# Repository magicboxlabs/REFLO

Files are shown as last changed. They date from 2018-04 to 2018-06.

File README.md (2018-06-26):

Setup
===================

1.In the BOX
-------------------
* **[Quick start guide](https://github.com/magicboxlabs/REFLO/blob/master/Documents/openthebox.pdf)** - Items in the box

2.Setup REFLO
-------------------
* **[Assemble guide](https://github.com/magicboxlabs/REFLO/blob/master/Documents/Assembly.pdf)** - Setup each modules
* **[Connect to the earth terminal](https://github.com/magicboxlabs/REFLO/blob/master/Documents/How%20to%20connect%20to%20the%20earth%20terminal.pdf)** - Additional working guide
* **[Setting the PCB](https://github.com/magicboxlabs/REFLO/blob/master/Documents/REFLO%20PAN%20USER%20GUIDE.pdf)** - REFLO PAN User Guide
* **[Warning](https://github.com/magicboxlabs/REFLO/blob/master/Documents/warning.pdf)** - Special Attention

3.Setup Software
-------------------
* **[iOS](https://itunes.apple.com/us/app/simblee-for-mobile/id1009048292?mt=8)** - iOS Mobile App
* **[Android](https://play.google.com/store/apps/details?id=com.simblee.simbleeformobile&hl=en)** - Android Mobile App

4.How to Operate
-------------------
* **[Operation guide](https://github.com/magicboxlabs/REFLO/blob/master/Documents/operation.pdf)** - UI Operation

Design Information
===================

1.Mechanical Parts
-------------------
* **[Mechanical Parts Data](https://github.com/magicboxlabs/REFLO/tree/master/parts)** - Chassis, 3D print parts, Furnace

2.PWB
-------------------
* **[Schematic Drawing](https://github.com/magicboxlabs/REFLO/blob/master/schematic/REFLO%20schematic.pdf)** - Gerber Data, Parts List
* **[PWB Data](https://github.com/magicboxlabs/REFLO/tree/master/gerber)** - Gerber Data, Parts List

3.Software
-------------------
* **[Source Code for iOS](https://github.com/magicboxlabs/REFLO/tree/master/software)** - Control Software Source Code
* **[Source Code for Android](https://github.com/magicboxlabs/REFLO/tree/master/software)** - Control Software Source Code

Reference
===================
* **[CrowdSupply REFLO](https://www.crowdsupply.com/magicbox/reflo)**
* **[Hacksterio REFLO](https://www.hackster.io/magicbox/ble-reflow-oven-controller-reflo)**
* **[Hacksterio SHAKEYs](https://www.hackster.io/ebaera/voice-controlled-shakeys)**
* **[Hacksterio actual example](https://www.hackster.io/tka1988/baking-your-pcbs-with-super-compact-reflow-oven-388e2c)**

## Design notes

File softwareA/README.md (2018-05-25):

Software for Android
-------------------
* **[Simblee](https://www.simblee.com/Simblee_Quickstart_Guide_v1.1.0.pdf)** - Arduino IDE for Simblee setup

* Modify variant file
Arduino/Contets/Java/portable/packages/Simblee/hardware/Simblee/1.0.0/variants/Simblee/variant.h     
  #define SPI_INTERFACE        NRF_SPI0  
  #define PIN_SPI_SS           (18u) //  
  #define PIN_SPI_MOSI         (30u) //  
  #define PIN_SPI_MISO         (16u) //  
  #define PIN_SPI_SCK          (17u) //  

* **[Library](https://github.com/FastLED/FastLED)** - RGB RED (FastLED) library

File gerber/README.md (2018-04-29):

Parts List
-------------------
* MPU with BLE - **[RFD77101](https://www.mouser.com/ProductDetail/RF-Digital-Wireless/RFD77101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)** 
* USB Interface FTDI - **[FT231XQ-R](https://www.mouser.com/ProductDetail/FTDI/FT231XQ-R?qs=sGAEpiMZZMvVkErl6zY%252bqYuXoSRwsvKy)**
* USB Connector - **[ZX62D-B-5PA8(30)](https://www.mouser.com/ProductDetail/Hirose-Connector/ZX62D-B-5PA830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)**
* Thermocouple Sensor - **[MAX31855KASA+](https://www.mouser.com/ProductDetail/Maxim-Integrated/MAX31855KASA%2b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)** 
* Motor Driver for Fan/Solenoid - **[DRV8838DSGR](https://www.mouser.com/ProductDetail/Texas-Instruments/DRV8838DSGR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)**
* DC-DC Converter - **[LP2985-33DBVR](https://www.mouser.com/ProductDetail/Texas-Instruments/DRV8838DSGR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)**

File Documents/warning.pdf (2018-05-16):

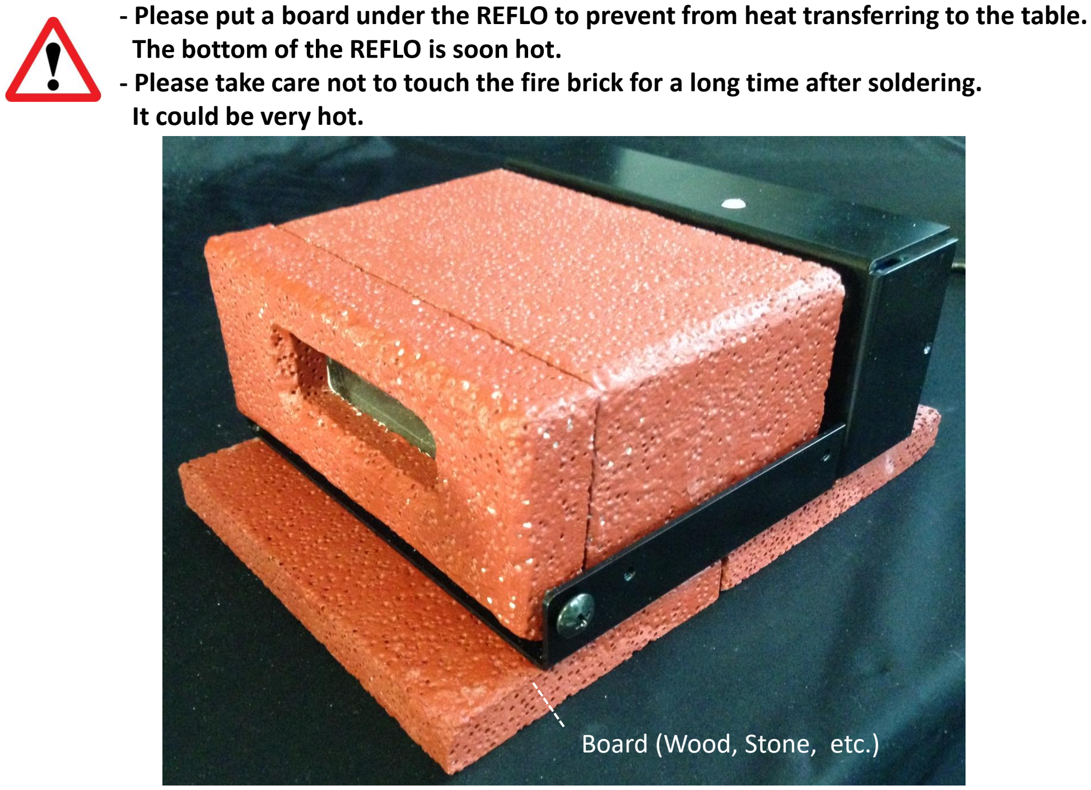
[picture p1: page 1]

Board (Wood, Stone, etc.)

- Please put a board under the REFLO to prevent from heat transferring to the table. The bottom of the REFLO is soon hot.
- Please take care not to touch the fire brick for a long time after soldering.
It could be very hot.

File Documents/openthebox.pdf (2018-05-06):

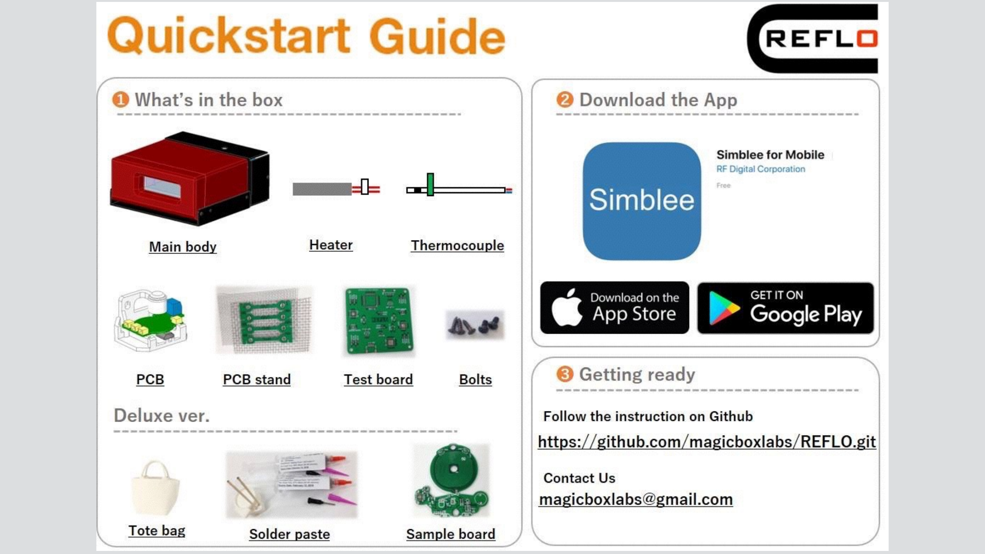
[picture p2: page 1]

Solenoid

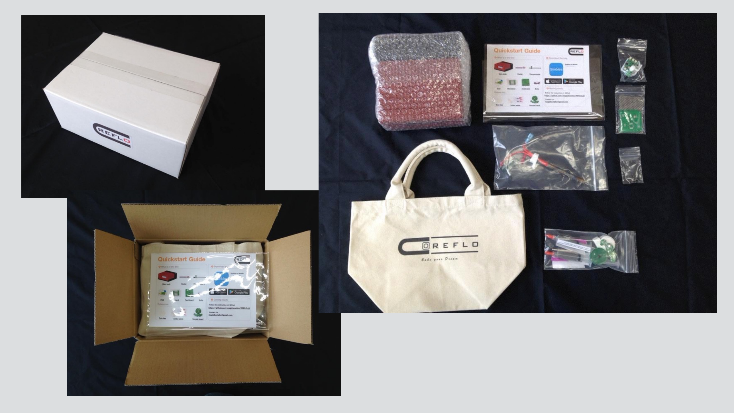
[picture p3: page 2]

Solenoid

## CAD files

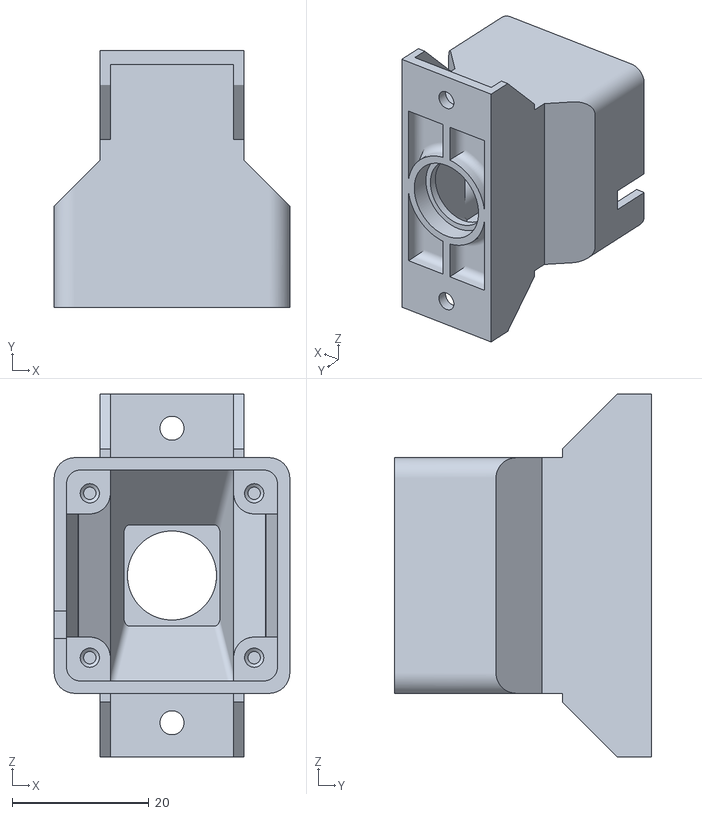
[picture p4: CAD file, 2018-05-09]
parts/Fan Case.stl
34.4 x 37.5 x 53.0

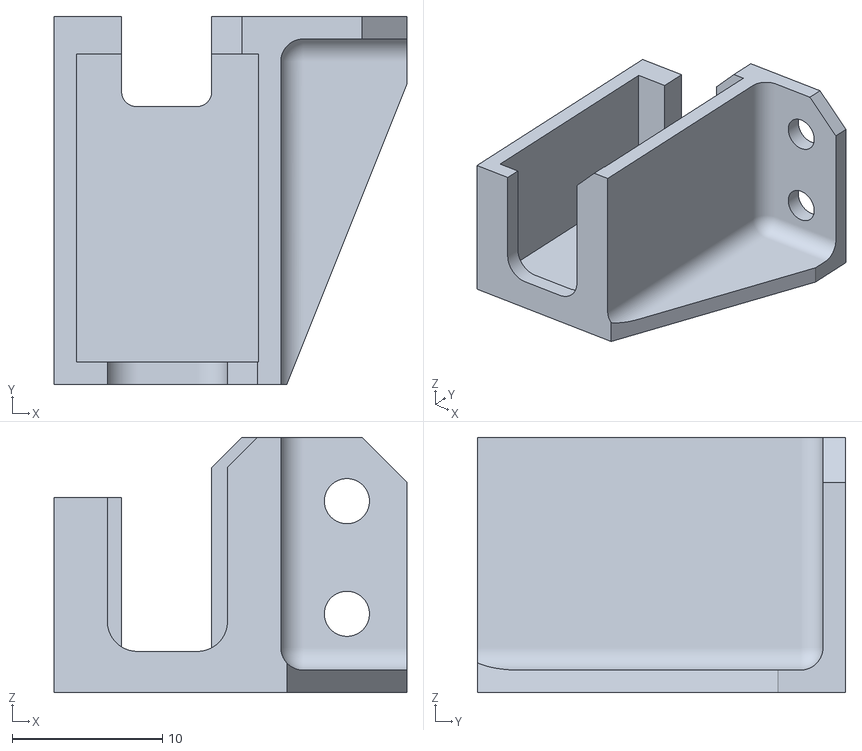
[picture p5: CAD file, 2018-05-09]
parts/Solenoid Holder.stl
23.5 x 24.5 x 17.0

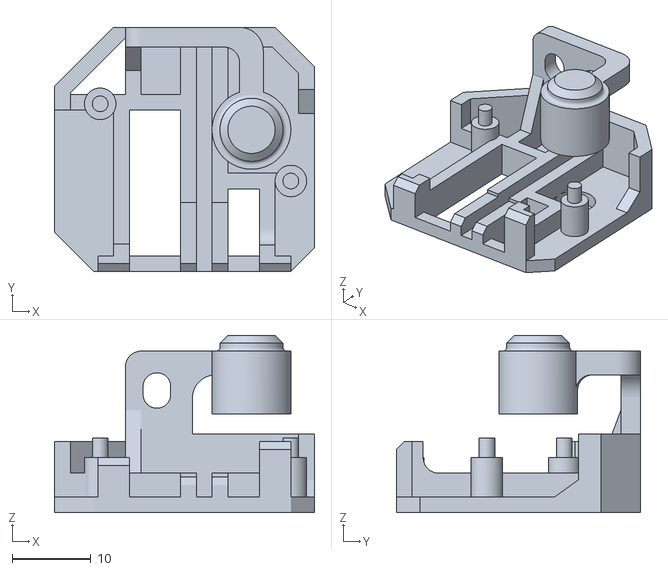
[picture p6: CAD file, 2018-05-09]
parts/PCB CASE.stl
33.0 x 31.0 x 22.5

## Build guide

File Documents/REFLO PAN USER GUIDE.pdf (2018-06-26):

## REFLO PAN USER GUIDE

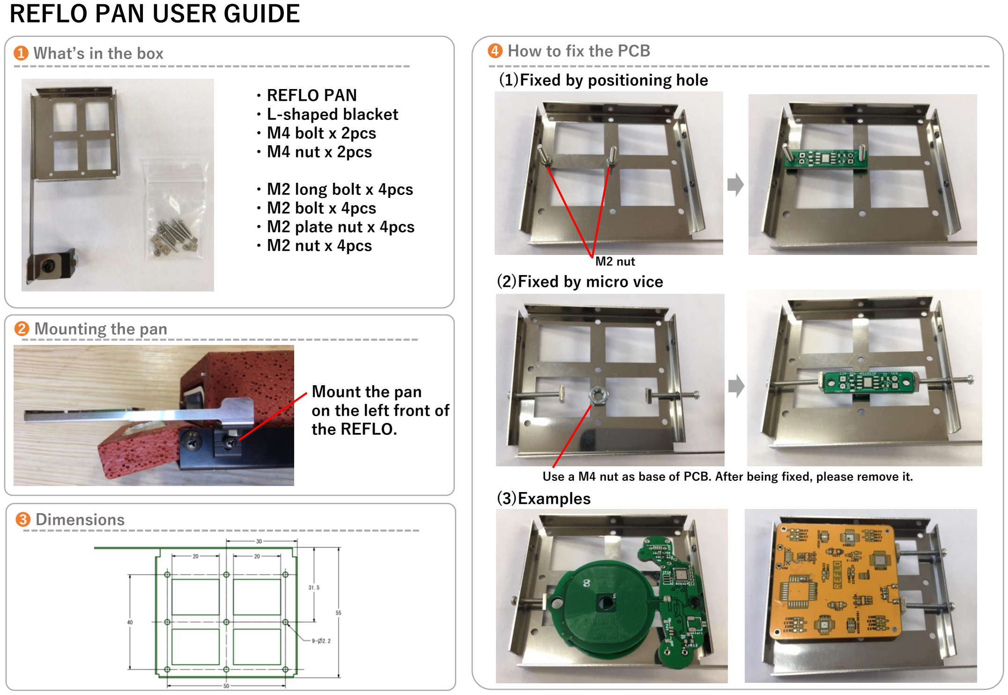
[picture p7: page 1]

❶ What’s in the box | ❹ How to fix the PCB

・REFLO PAN
・L-shaped blacket
・M4 bolt x 2pcs
・M4 nut x 2pcs

・M2 long bolt x 4pcs
・M2 bolt x 4pcs
・M2 plate nut x 4pcs
・M2 nut x 4pcs

❷ Mounting the pan

Mount the pan
on the left front of
the REFLO.

❸ Dimensions

(1)Fixed by positioning hole

(2)Fixed by micro vice

(3)Examples

Use a M4 nut as base of PCB. After being fixed, please remove it.

M2 nut

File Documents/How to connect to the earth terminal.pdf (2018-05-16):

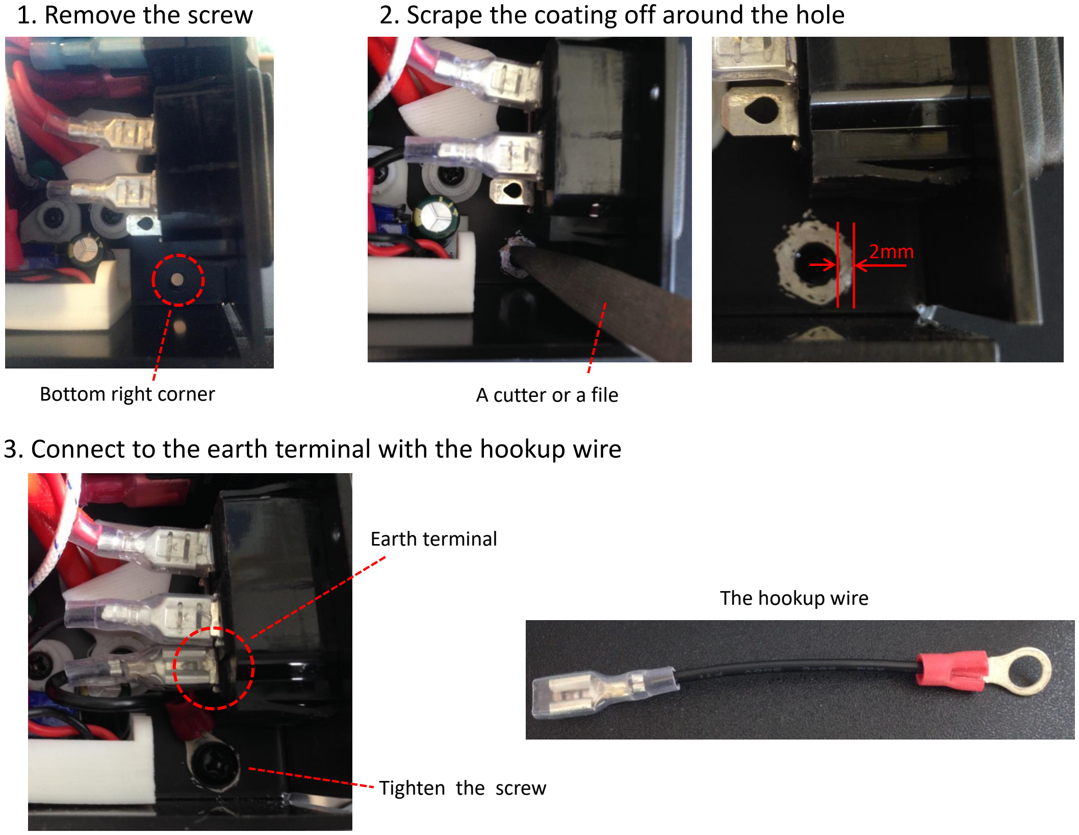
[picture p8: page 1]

1. Remove the screw

Bottom right corner

2. Scrape the coating off around the hole

A cutter or a file

2mm

3. Connect to the earth terminal with the hookup wire

Earth terminal

The hookup wire

Tighten the screw

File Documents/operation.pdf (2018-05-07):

## Starting Application

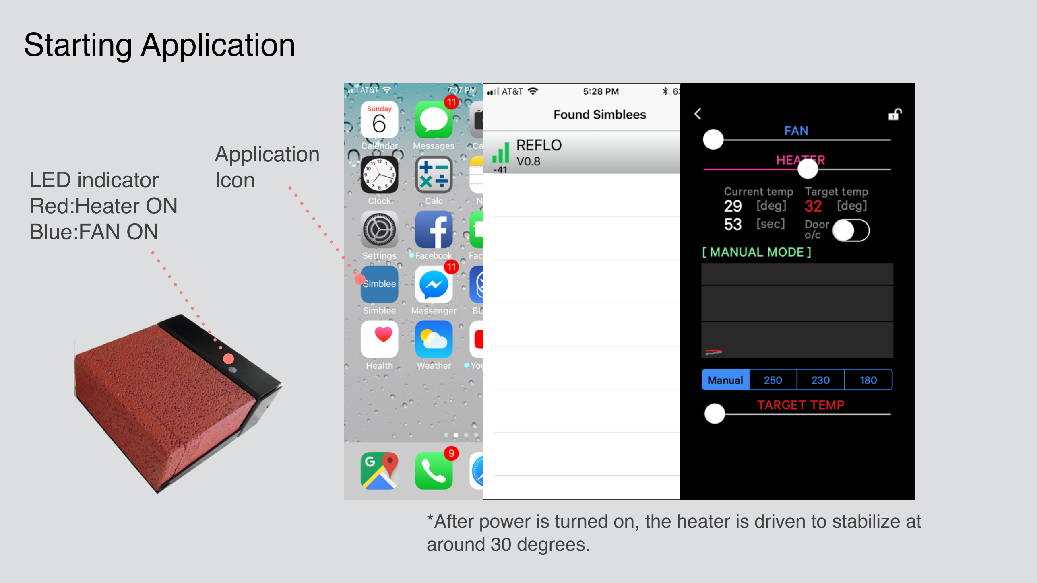
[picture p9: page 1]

Application
Icon

LED indicator
Red:Heater ON
Blue:FAN ON

*After power is turned on, the heater is driven to stabilize at around 30 degrees.

## Manual Mode

Temperature
setting slider

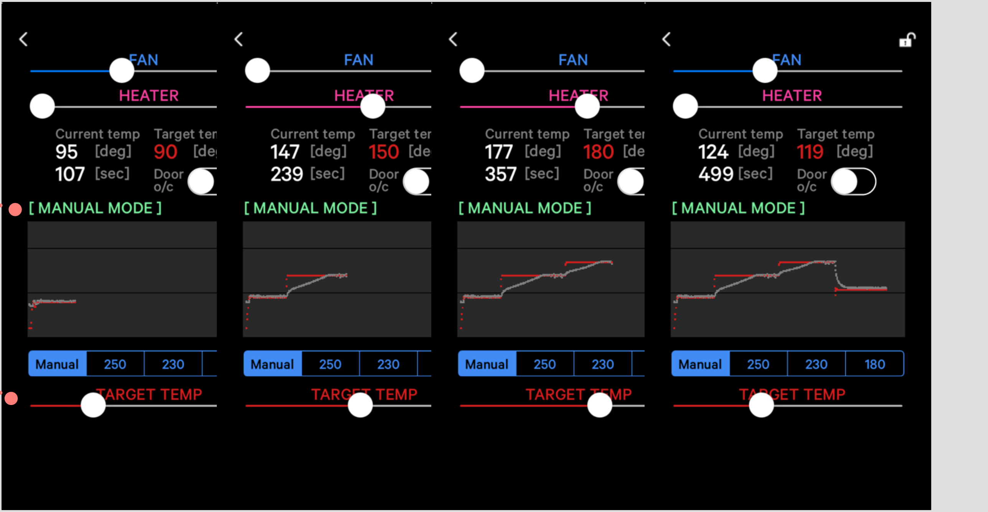
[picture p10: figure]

Set to 90 degrees
by slider

Set to 150 degrees
by slider

Set to 180 degrees
by slider

Set to 119 degrees
by slider

*You can set it to any temperature with the temperature setting slider. The heater and fan automatically adjust the temperature.

Mode
Display

Auto Mode | *Three kinds of temperature profile of 180/230/250 degrees are selected, and heater and fan can work together to automatically execute temperature profile.

Temperature
profile
selector

Mode
Display

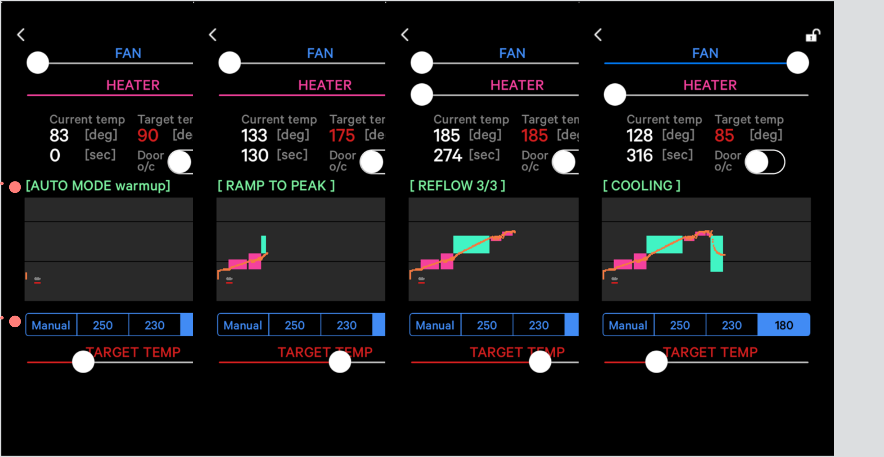
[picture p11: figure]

Warmup | Ramp to Peak
after Soak stage | Reflow stage | Cooling down stage

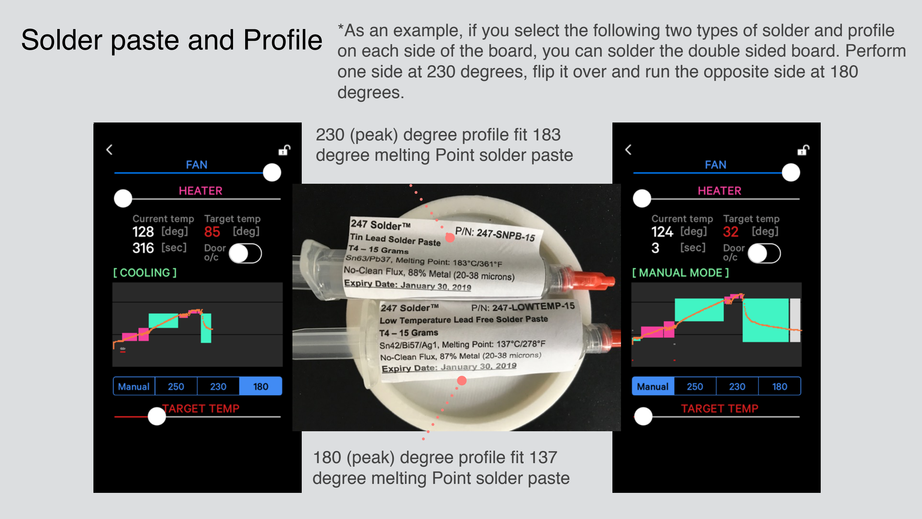
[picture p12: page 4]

Solder paste and Profile *As an example, if you select the following two types of solder and profile on each side of the board, you can solder the double sided board. Perform one side at 230 degrees, flip it over and run the opposite side at 180 degrees.

230 (peak) degree profile fit 183 degree melting Point solder paste

180 (peak) degree profile fit 137 degree melting Point solder paste

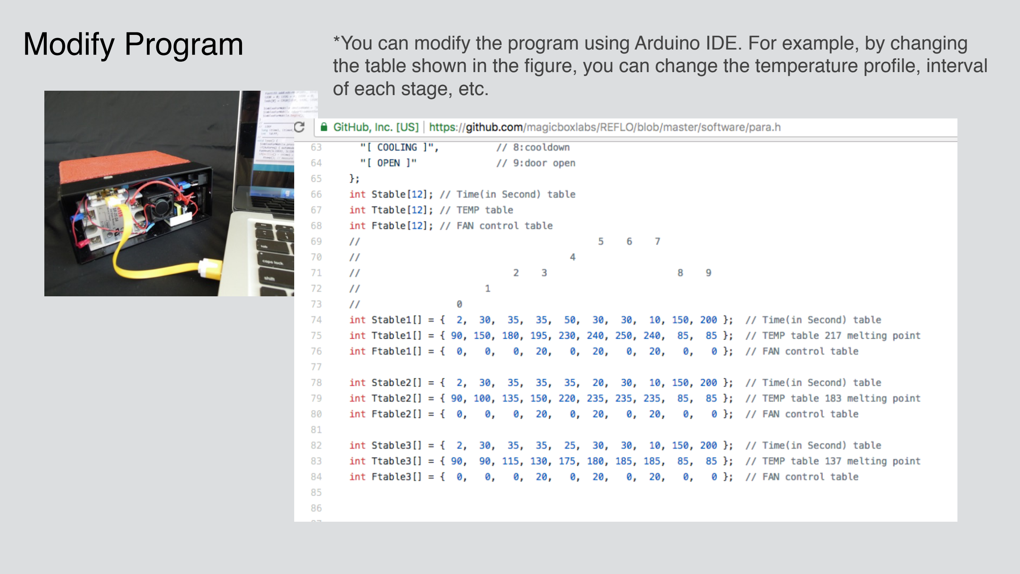
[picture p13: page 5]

Modify Program | *You can modify the program using Arduino IDE. For example, by changing the table shown in the figure, you can change the temperature profile, interval of each stage, etc.

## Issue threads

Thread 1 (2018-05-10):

REFLO lacks chassis ground connection

jmwilson, 2018-05-10:
The assembly directions for REFLO show an unconnected ground tab on the power entry unit, and the unit I received looks the same. I'm concerned this presents a serious electrical shock hazard. Without a chassis ground connection, if there is an electrical fault inside the REFLO, then the metal case can become electrically live at utility voltage (120 VAC in NA). I'd like to suggest emailing all recipients of the REFLO to inform them of this problem, and shipping a ground connection wire to all recipients. I fashioned a connection using hookup wire a pair of crimp terminals.

TKA1988, 2018-05-15:
[How to connect to the earth terminal.pdf](https://github.com/magicboxlabs/REFLO/files/2006779/How.to.connect.to.the.earth.terminal.pdf)
This guide will show you how to connect to the earth terminal. If you need the hookup wire, I will send you.

nikwest, 2018-05-16:
Yes, I did it exactly the same way as TKA1988 suggested.

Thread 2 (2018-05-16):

No simblee connection with Android

TKA1988, 2018-05-16:
Here is the report from Android user.
---------------------------------------------------------------------------------------------------
The REFLO powers up and stabilizes at the preset initial temperature. I can see and Bluetooth pair with the REFLO from the phone and from a computer. So the REFLO does appear to be working correctly.

However the Simblee app (Android) does not seem to connect. It prints the lines "Found Simblees" and "Select Simblee" regardless of whether the REFLO is turned on or not. No other display or interaction appears possible. I've also uninstalled and reinstalled the app, making sure it has been given all requested permissions.

It looks as though my Android 8.0.0 phone (Sony Xperia XZ) is not supported. It does connect with my Galaxy S tablet (Android 6.0.1) but the app doesn't work correctly (repeatedly disconnects, can't control temperature in Manual mode).

It would seem I'm stuck until Simblee provides Android 8.0 support. Could it be possible to communicate with the controller via a BLE serial terminal session or directly through the USB connector? Seems unfortunate to be this close!

TKA1988, 2018-05-27:
The software for Android was updated. Please check the following.
https://github.com/magicboxlabs/REFLO/tree/master/software

ppelleti, 2018-10-03:
> The software for Android was updated. Please check the following.
> https://github.com/magicboxlabs/REFLO/tree/master/software

So, to be clear, I need to recompile the software and upload it to the REFLO using the USB connector on the circuit board?

TKA1988, 2018-10-04:
Yes, you need to do. And don't forget to power supply from DC converter to the PCB when you upload it.

jdimpson, 2019-01-04:
I need more help than this. I can get simblee for mobile on Android to connect and start a bake, but after that the app will not stay connected.

Are you saying the fix is to change the Arduino code on the reflo?  Where are the instructions for this? The simblee.com link provided in REFLO/software folder is broken.

Does this mean that I need different Arduino code on the REFLO depending on whether I control via Apple or Android? This simblee stuff is terrible.

What do you mean "don't forget to power supply from DC converter to the PCB when you upload it." Do you mean to provide DC power to the internal board? How? How do I upload the firmware? I assume it had a serial or usb header, but where can I see the documentation for that?

TKA1988, 2019-01-05:
@jdimpson Yes, you need to change the Arduino code on the PCB by micro USB. I attached quick start guide for Simblee IDE installation. When you upload the code, you have to turn on power switch of REFLO so that it supplies 5V to the PCB. The code for Android is [here.]  (https://github.com/magicboxlabs/REFLO/tree/master/software)
If it is not going to work, we could send you the PCB optimized for Android.
We are sorry for inconvenience. Please keep us updated on this matter.
[Simblee_Quickstart_Guide_v1.0.pdf](https://github.com/magicboxlabs/REFLO/files/2729275/Simblee_Quickstart_Guide_v1.0.pdf)

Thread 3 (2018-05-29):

Missing step in Assembly Instructions for wood screws on in back panel

jdimpson, 2018-05-29:
Hello!

This is relatively minor. The [Assembly Instructions](https://github.com/magicboxlabs/REFLO/blob/master/Documents/Assembly.pdf) should mention to use the wood screws to hold the back wood panel into the housing.

Also, I originally received 3 wood screws and 2 machine screws. I only used 2 wood screws and 1 machine screw. Is that the expected result? Thanks.

TKA1988, 2018-05-31:
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

Thanks for your comment. I attached the screw arrangement at the back-side.

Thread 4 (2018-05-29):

Request instructions for PCB stand

jdimpson, 2018-05-29:
Could you provide instructions for assembling and use the PCB stand? Or perhaps they already exist and I missed them. Thanks!

TKA1988, 2018-05-31:
You can download the stl data as follow and build it with 3D printer.
https://github.com/magicboxlabs/REFLO/blob/master/parts/PCB%20CASE.stl

Thanks,

ppelleti, 2018-10-03:
Perhaps I misunderstood the question, but I think @jdimpson was referring to this:

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

Although I can make a few guesses, it's not entirely obvious to me how this is meant to be assembled.

TKA1988, 2018-10-04:
Oh, I misunderstood that. Here is the assembled PCB stands.
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
You can put it inside the REFLO.
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
But if you have a REFLO pan, you don't need to use the stand.

jdimpson, 2018-10-12:
Yes, I was referring to this. But I use the pan now. Thank you!

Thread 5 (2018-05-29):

Request parts BOM for Test Board and Sample Board

jdimpson, 2018-05-29:
Is there a Bill of Materials that I can use to get components so I can bake the Test Board and Sample Board? Thanks!

TKA1988, 2018-05-31:
You can access to the information about Sample Board as follow.
https://www.hackster.io/ebaera/voice-controlled-shakeys-b93512

Thanks,

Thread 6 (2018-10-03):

Need to connect fan in assembly instructions

ppelleti, 2018-10-03:
In the assembly instructions, there is no mention of connecting the fan to the circuit board.  However, from the pictures I can see this was done in between the "Connect solenoid" and "Connect Solid State Relay" steps.

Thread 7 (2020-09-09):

Simblee replacement?

nikwest, 2020-09-09:
Unfortunately Simblee does not exist anymore and also the old version does not work anymore. Is anybody still using REFLO? is there a way to control it without Simblee?

TKA1988, 2020-09-11:
@nikwest We are planning to make a stand-alone version of REFLO as attached.  We could send you the parts kit for it when we get ready.
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

nikwest, 2020-09-30:
ok, maybe I just also look at the code for now to see if I can do something myself.

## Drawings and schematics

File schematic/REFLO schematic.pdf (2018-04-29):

# REFLO

## 1. VCC

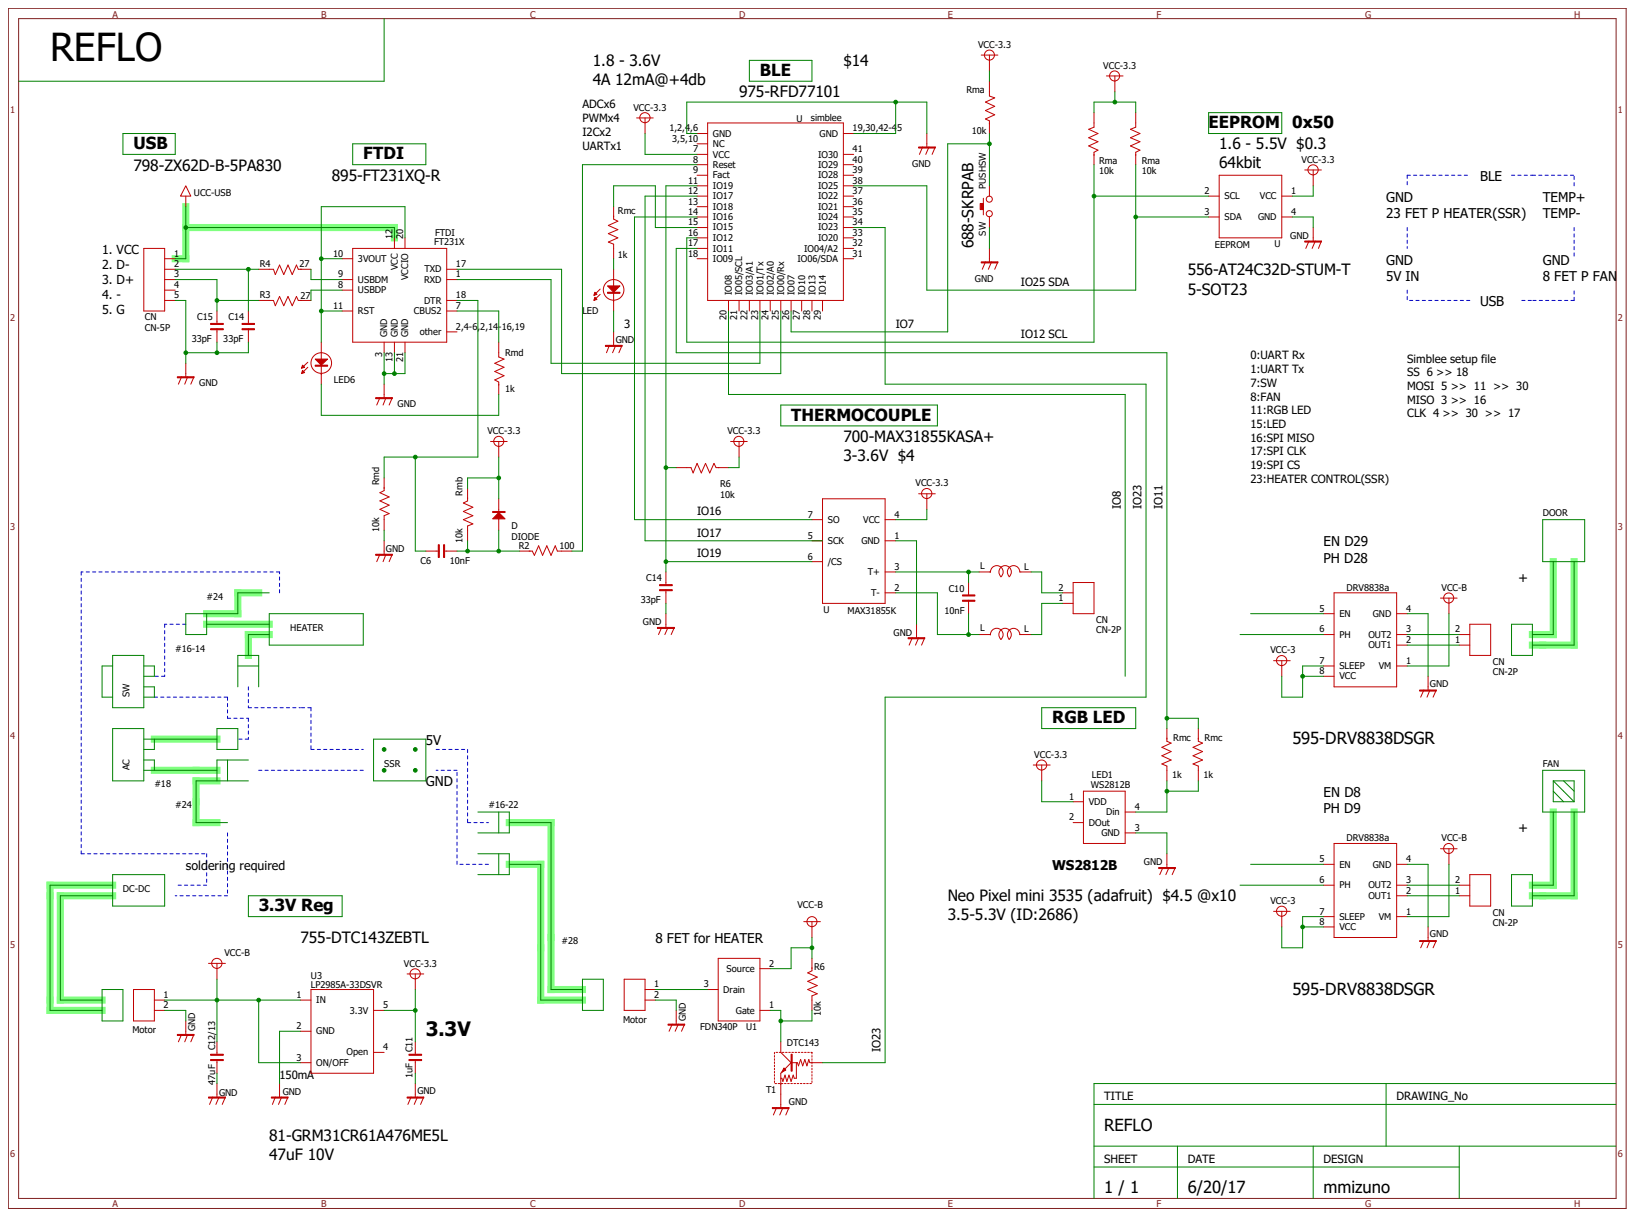
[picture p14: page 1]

0:UART Rx 1:UART Tx 7:SW

Simblee setup file SS 6 >> 18 MOSI 5 >> 11 >> 30 MISO 3 >> 16 CLK 4 >> 30 >> 17

Neo Pixel mini 3535 (adafruit) $4.5 @x10

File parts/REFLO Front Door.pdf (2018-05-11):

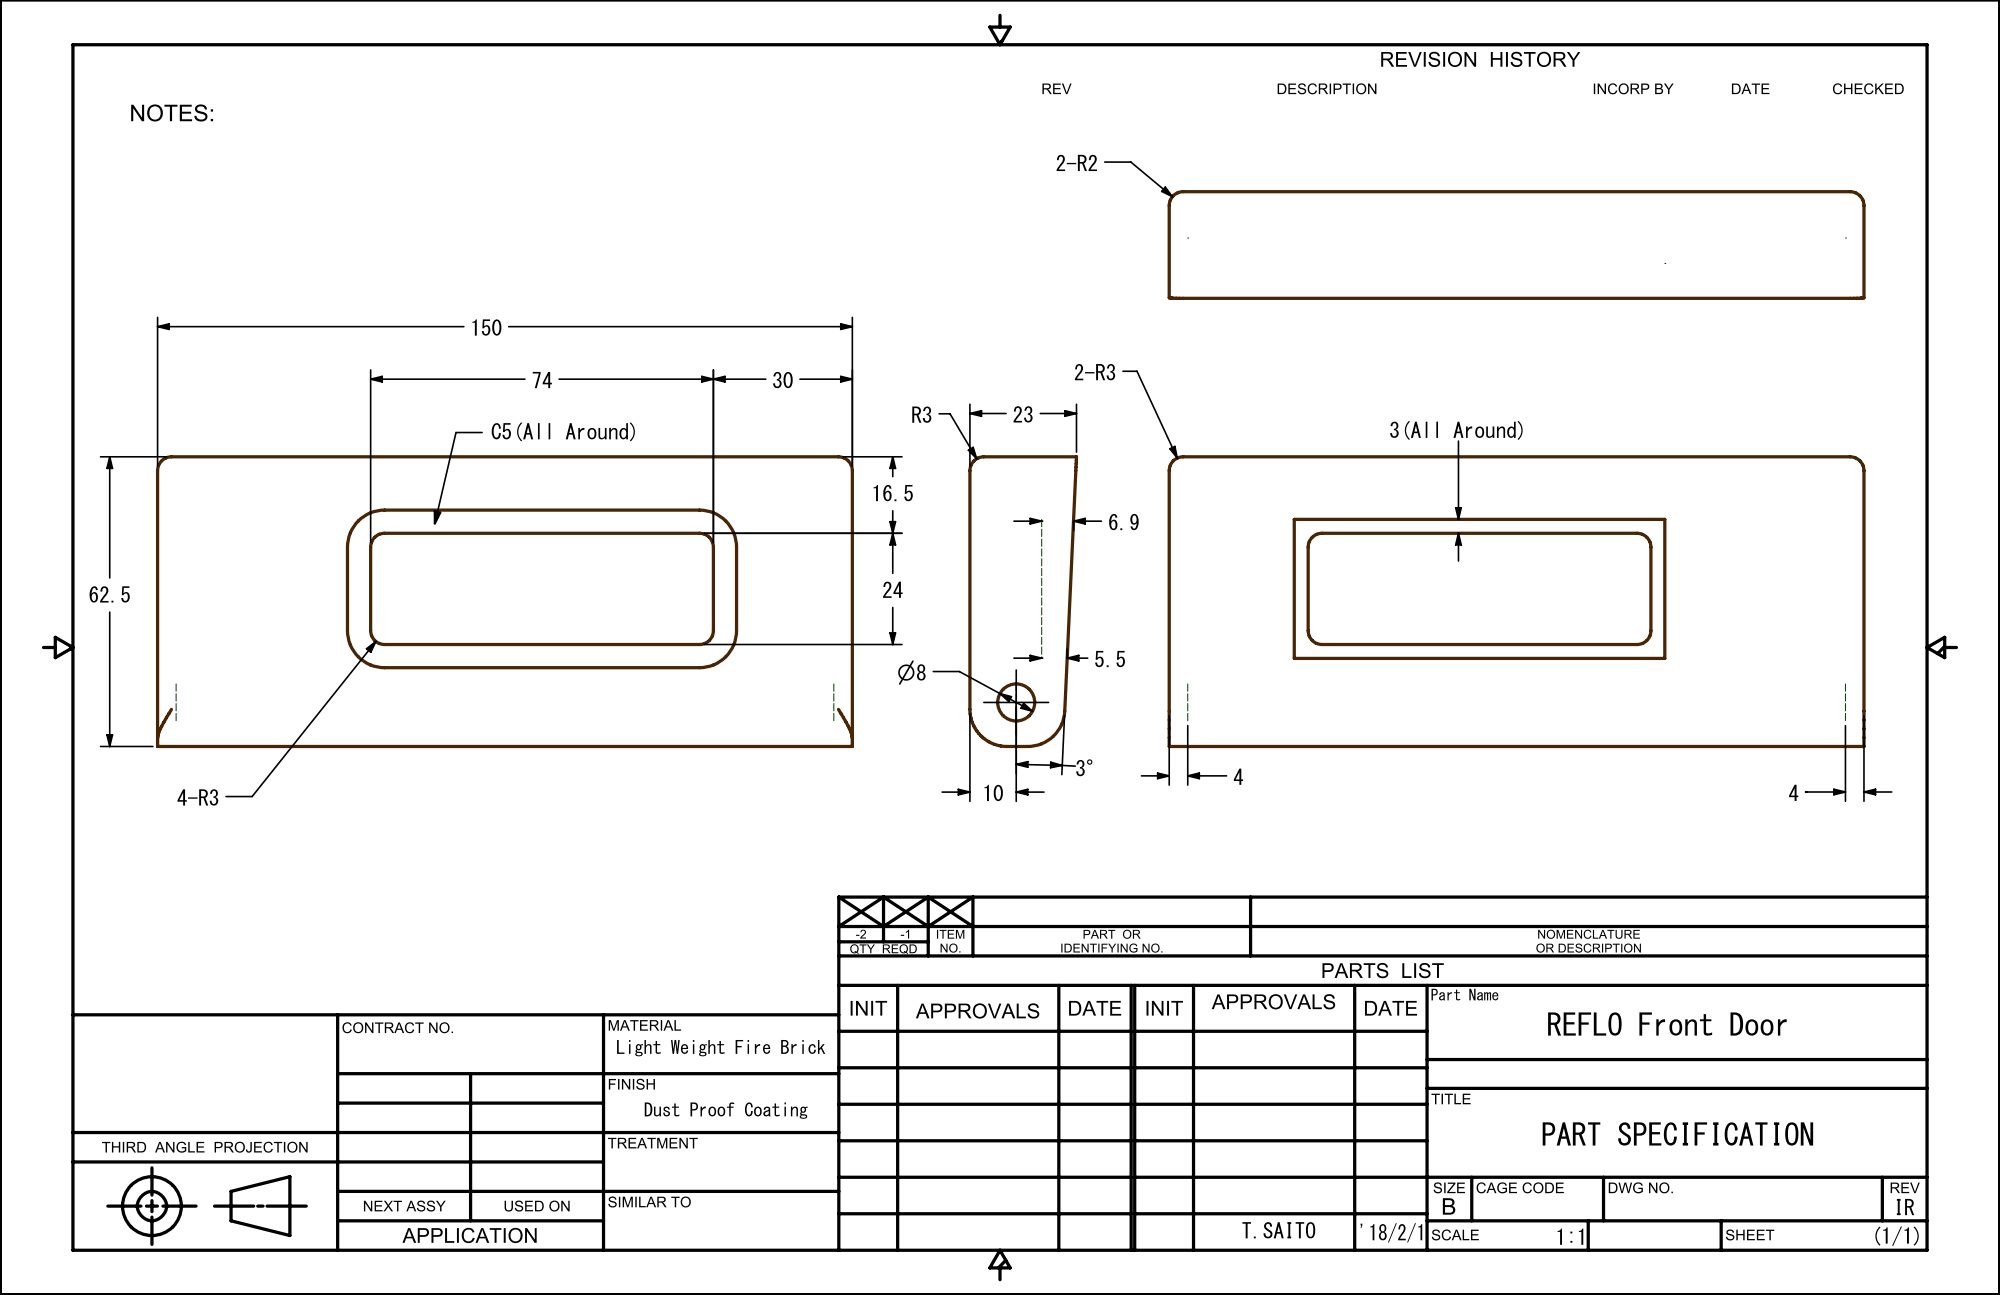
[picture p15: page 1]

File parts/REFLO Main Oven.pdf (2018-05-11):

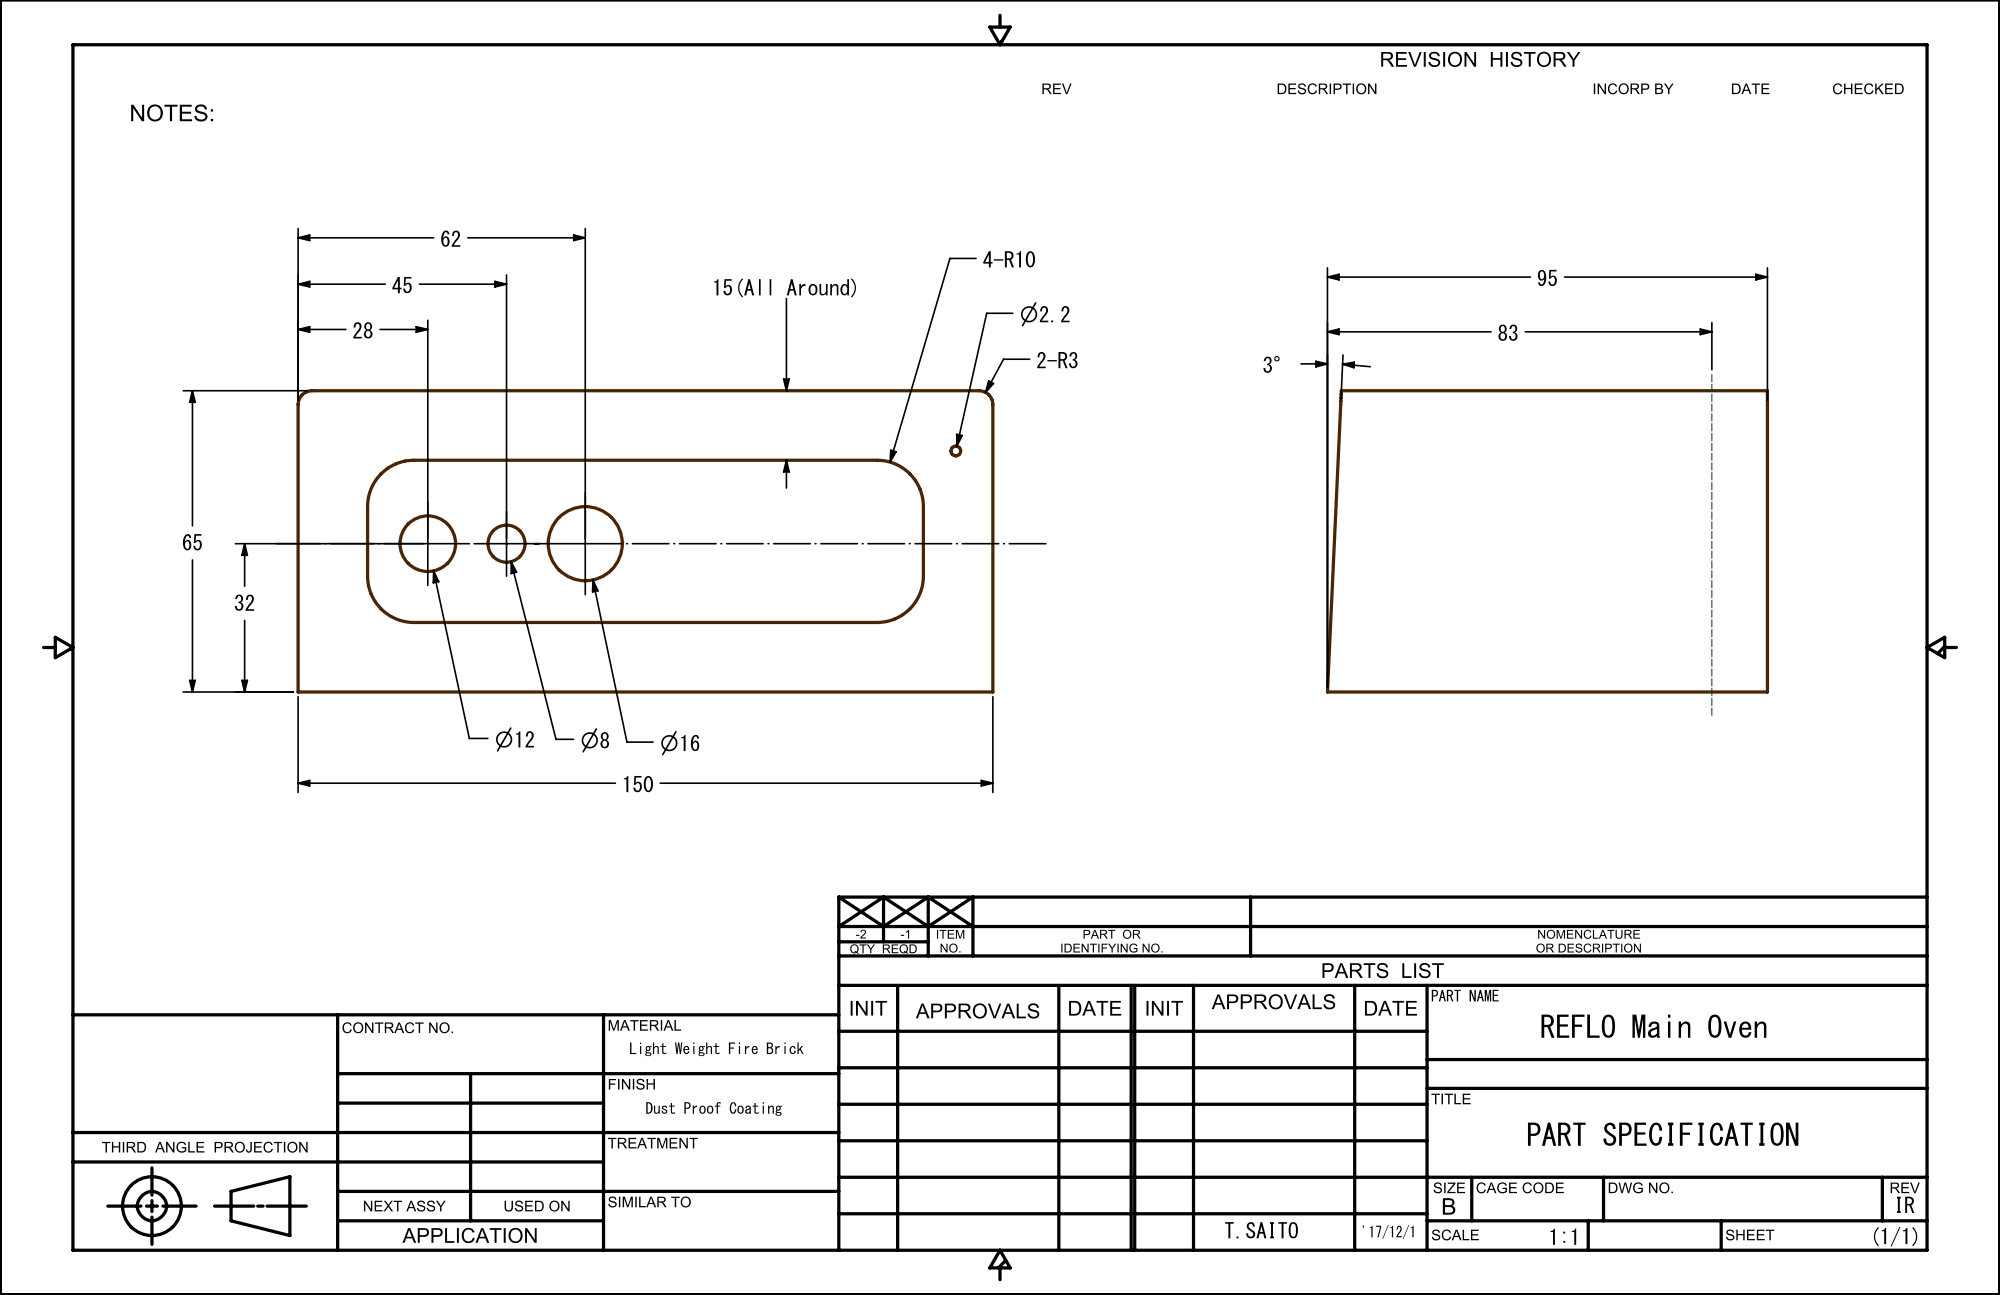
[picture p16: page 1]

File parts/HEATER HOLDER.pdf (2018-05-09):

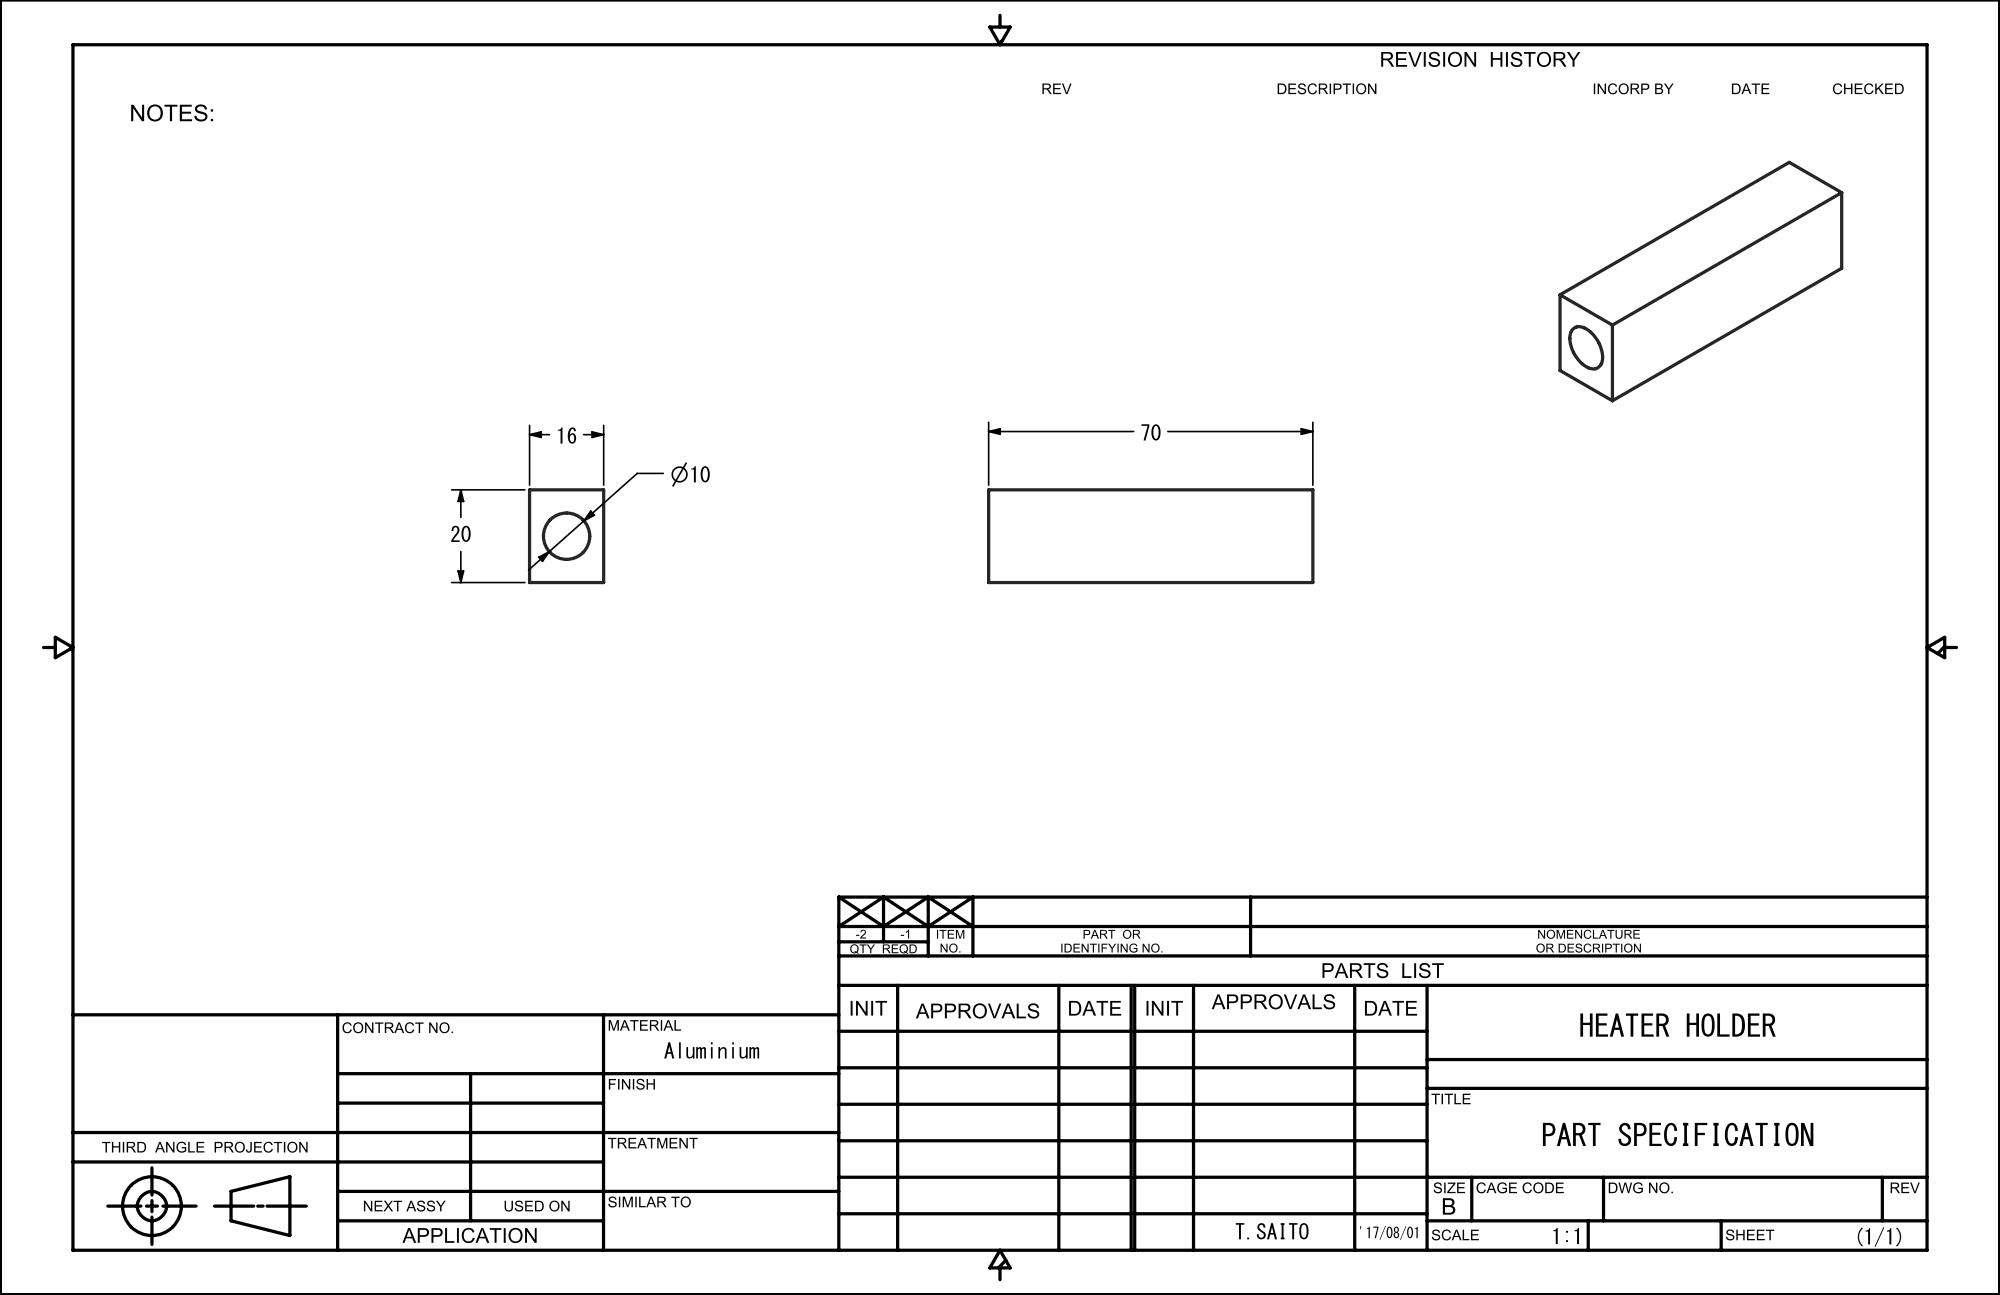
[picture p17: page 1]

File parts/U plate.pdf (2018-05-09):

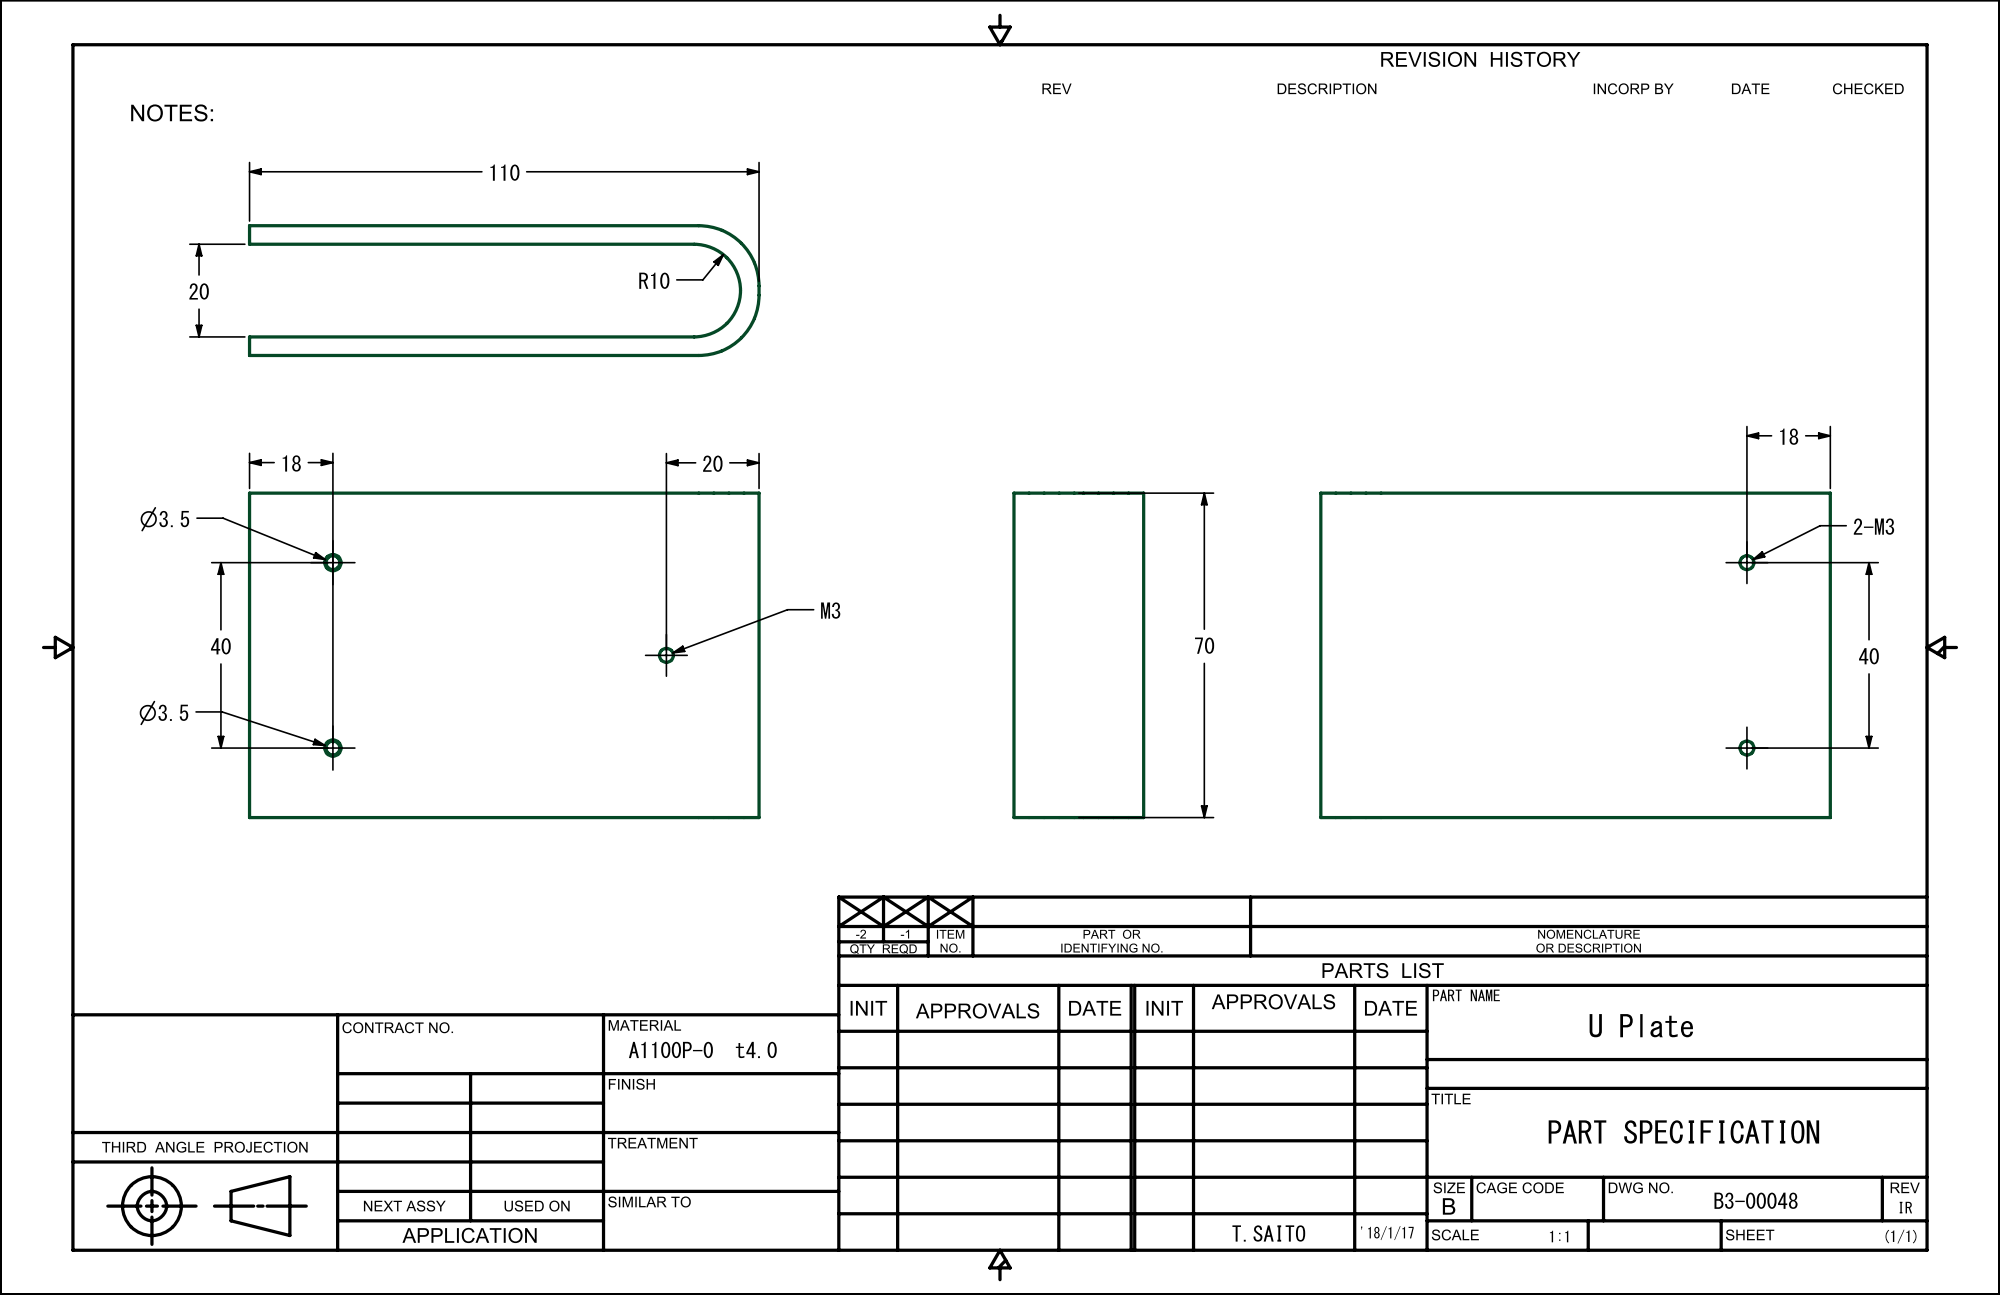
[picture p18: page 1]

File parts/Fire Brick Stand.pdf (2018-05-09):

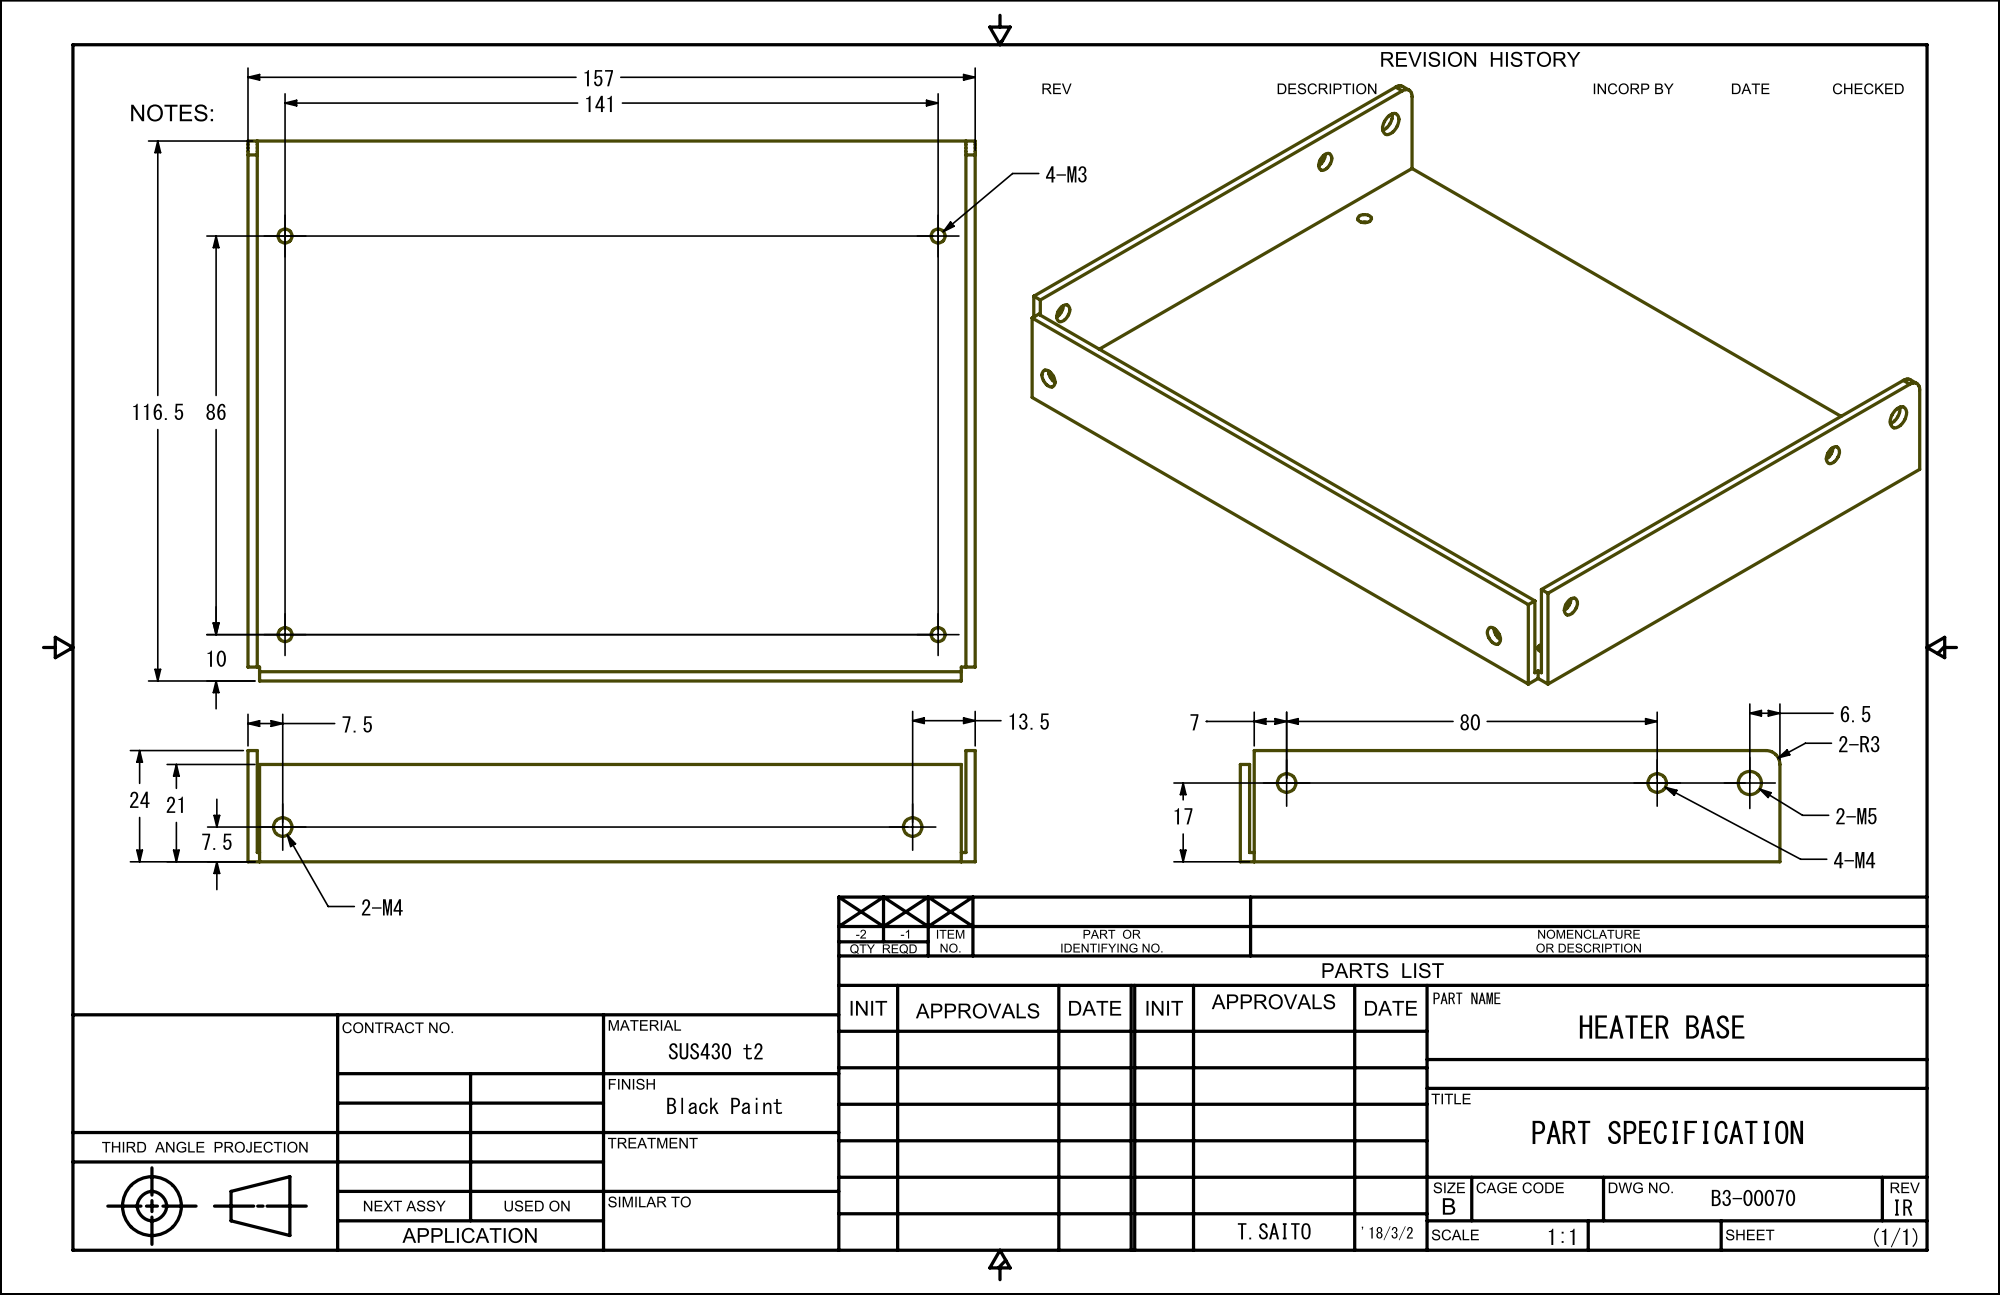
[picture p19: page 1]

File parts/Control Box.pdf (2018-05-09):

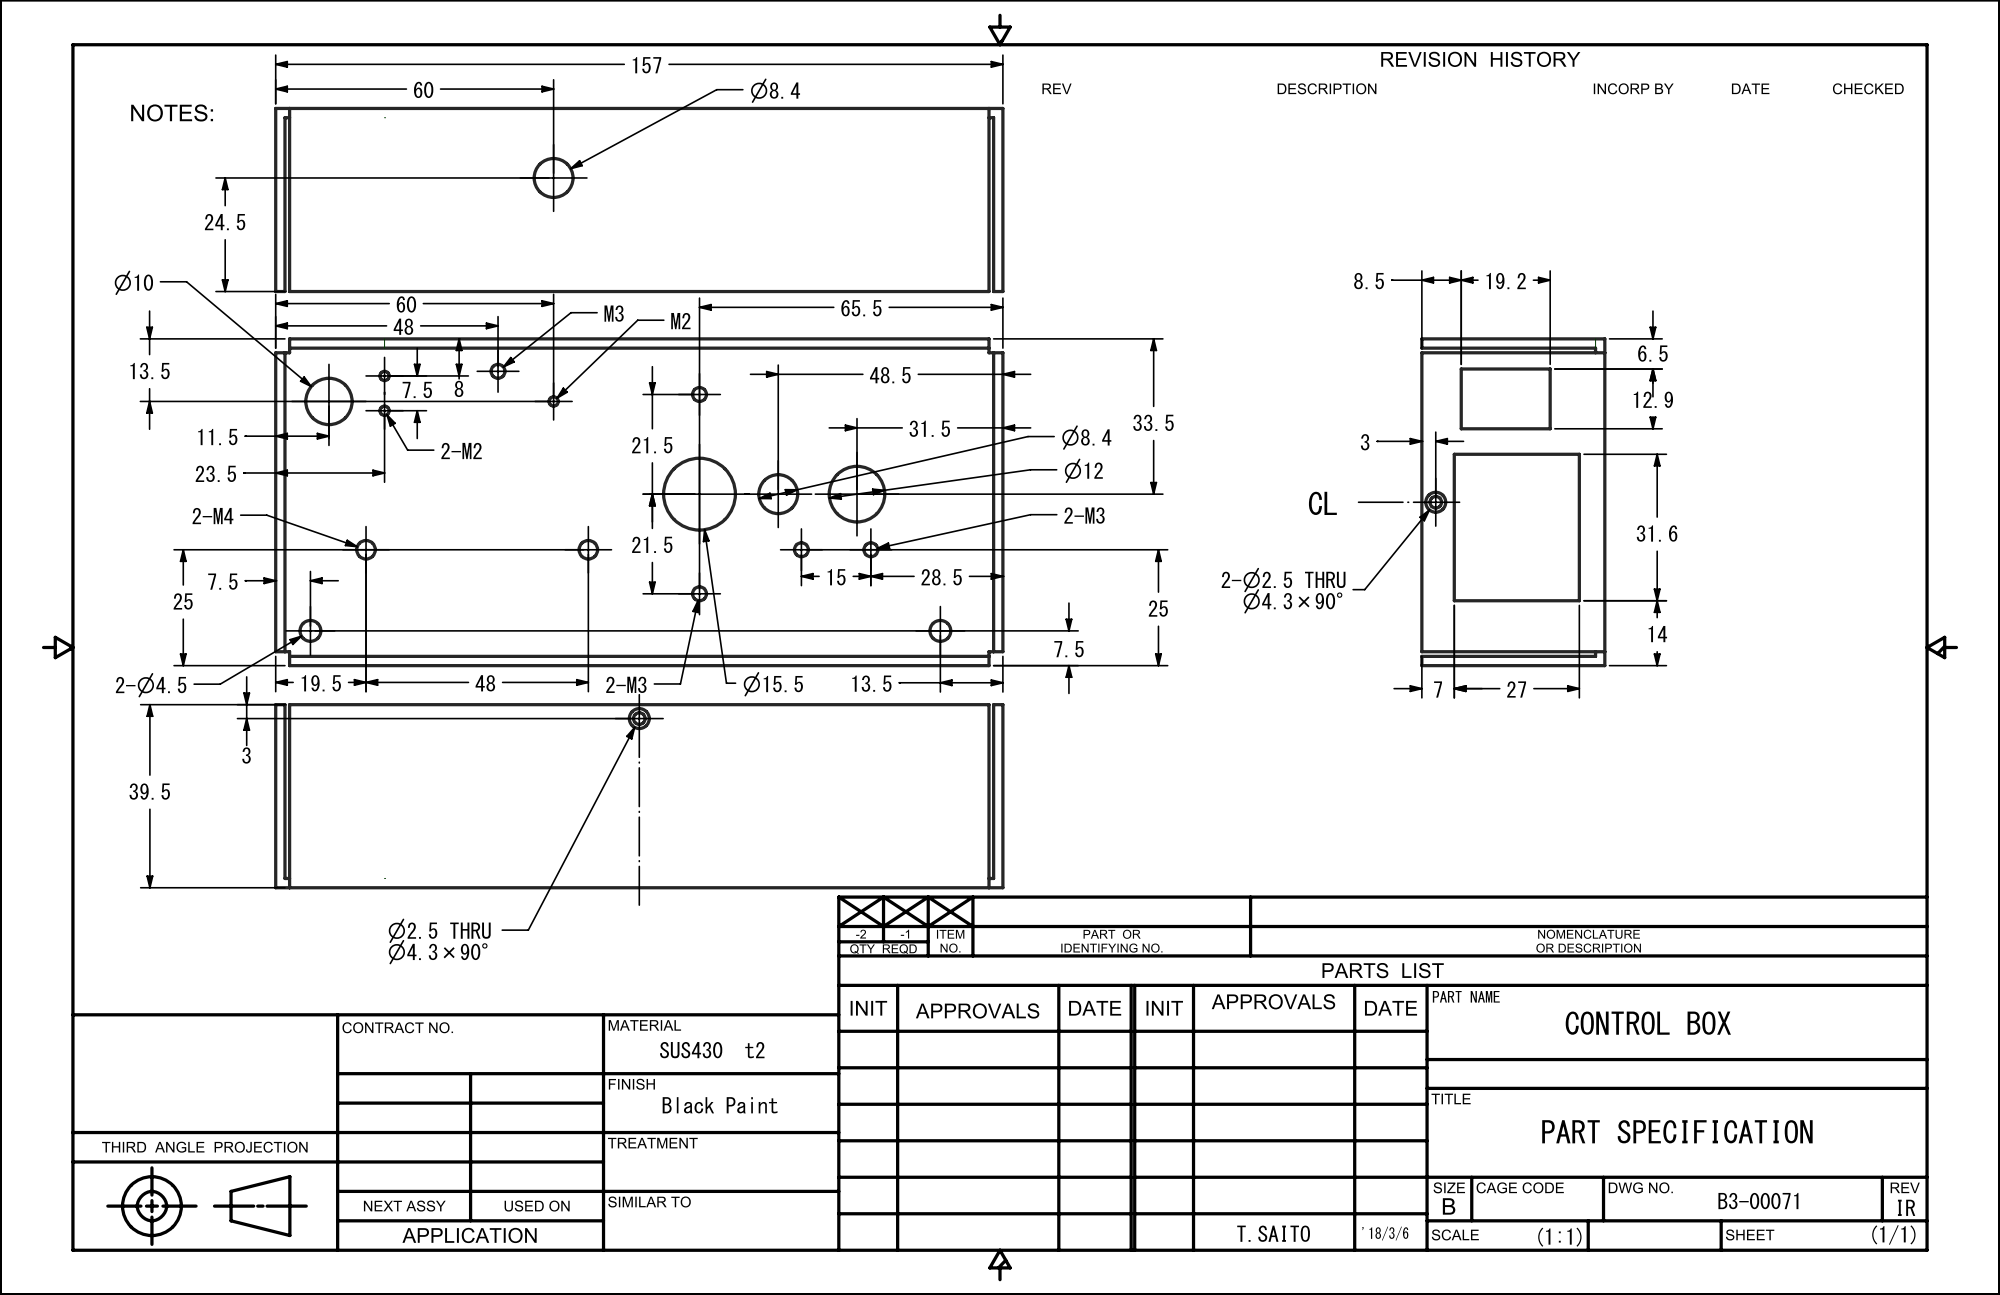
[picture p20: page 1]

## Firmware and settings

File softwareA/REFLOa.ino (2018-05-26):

// ============================================
//  Base design http://simblee.com
//  Language Reference http://arduino.cc/en/Reference/HomePage
//  24kRAM, 128kROM
// ============================================
//  FILE INCLUDE 
// ============================================
  #include "FastLED.h"                // RGB LED
  #include "SimbleeForMobile.h"       // BLE
  #include "SPI.h"                    // Thermocouple
  #include "para.h"                   //     

  CRGB leds[1];                       // RGB LED buffer   
// ============================================
//  SETUP
// ============================================
void setup() {
  Serial.begin(9600);                         // for Serial Monitor
  SPI.begin();                                // SPI CLK:17 SPI MISO:16 (MOSI:30)
  pinMode(15, OUTPUT);                        // LED    
  pinMode(19, OUTPUT);  digitalWrite(19, 1);  // SPI CS
  pinMode( 7,  INPUT);                        // TACT SW
  pinMode( 8, OUTPUT);  digitalWrite(8,  0); // FAN PH
  pinMode( 9, OUTPUT);  digitalWrite(9,  0);  // FAN ENABLE
  pinMode(23, OUTPUT);  digitalWrite(23, 0);  // HEATER  
  pinMode(28, OUTPUT);  digitalWrite(28, 1);  // DOOR PH
  pinMode(29, OUTPUT);  digitalWrite(29, 0);  // DOOR ENABLE

  FastLED.addLeds<NEOPIXEL, 11>(leds, 1);     // FastLED setup for RGB LEDs      
  StatusLED();
  
  SimbleeForMobile.deviceName = "REFLOa";         // device name
  SimbleeForMobile.advertisementData = "V0.8";    // firmware version
  SimbleeForMobile.begin();                       // Formobile start  

  manualmodeSetup(); 
}
// ============================================
//  LOOP (SLIDER1:FAN, SLIDER2:HEATER, SLIDER3:TARGET)
  long itime1, itimeS;              // Timer controll
  int  Tdiff;                       // Temp difference    
  int  SFan;                        // Count
  int  Scnt;                        // 
// ============================================ 
void loop() {
  if(DOOR) { solenoid(); } SimbleeForMobile.process();     
  FanHeat(SLIDER1, SLIDER2);                          // fan/heater control    
  if(millis() - itimeS > 300) { itimeS = millis();    // stirrer fan control flg
    int stir = Ftable[SQpnt]; 
    if(!stir) { SFan = 0; } else { Scnt++; if(Scnt > stir) { Scnt = 0; SFan = 1; } if(Scnt > 2) { SFan = 0; } }
  }
  if(millis() - itime1 > 1000) { itime1 = millis();   // 1sec timer control
    StatusLED(); 
    TCtemp = Rtemp(); Tdiff = SLIDER3 - TCtemp;
    if(Tdiff > 0) { SLIDER1 = 0; /*14;*/             SLIDER2 = min(abs(Tdiff)*12, 64); } // heating
    else          { SLIDER1 = min(abs(Tdiff)*5, 64); SLIDER2 = 0;                      } // cooling    
    if(TCtemp < 70) { SLIDER1 = 0; }                // idle
    if(Autoreq) { automodeSetup(); Autoreq = 0; delay(1000); }       // selector change event 
    if(SELECT0 != 0) { // AUTO sequence mode ----------------------------------------          
       SQSQ--; if(!SQSQ) {
          if(SQpnt == 3 || SQpnt == 5 || SQpnt == 7) { loadNext(); } // load next table
          else { 
            if(SQpnt < countof(seqname) - 1 && TCtemp < SLIDER3 - 2) { SQSQ++; } else { loadNext(); } // postpone until reach to target temp
          }
       } if(!SQpnt && TCtemp < 90 && SQcnt > 0) { SQcnt--; pp = "[AUTO MODE warmup]"; } // warmup mode @cold start  
    }  uiupdate(); SQupdate();
  }
}
void loadNext() { 
  if(SQpnt < countof(seqname)) { SQpnt++; SLIDER3=Ttable[SQpnt]; SQSQ=Stable[SQpnt]; pp=seqname[SQpnt]; LAP=SQcnt; } 
}
void SQupdate() { SQcnt++; if(SQcnt > 540) { SQcnt = 0; if(SELECT0 != 0) { manualmodeSetup(); }}} // sequence control

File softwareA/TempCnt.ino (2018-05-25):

// ============================================
// status on LED
   boolean tgll;
// ============================================
void StatusLED() { leds[0] = CRGB(SLIDER2, 4, SLIDER1); FastLED.show(); digitalWrite(15, tgll); tgll = !tgll; }
// ============================================
// auto mode parameter setup
// ============================================
void manualmodeSetup() { SELECT0 = 0; // Auto mode reset
  SQpnt = 0; oldSQpnt = 99; pp = "[ MANUAL MODE ]"; 
  SLIDER1 = 0; SLIDER2 = 0; SLIDER3 = 32;
}
void automodeSetup() { //
  Serial.print("hya"); Serial.println(SELECT0);
  if(SELECT0 != 0) {
    if(SELECT0 == 1) { for (int n = 0; n < 9; n++) { Stable[n] = Stable1[n]; Ttable[n] = Ttable1[n]; Ftable[n] = Ftable1[n]; } }
    if(SELECT0 == 2) { for (int n = 0; n < 9; n++) { Stable[n] = Stable2[n]; Ttable[n] = Ttable2[n]; Ftable[n] = Ftable2[n]; } }
    if(SELECT0 == 3) { for (int n = 0; n < 9; n++) { Stable[n] = Stable3[n]; Ttable[n] = Ttable3[n]; Ftable[n] = Ftable3[n]; } } 
    SQcnt = 0; SQpnt = 0; LAP = 0;  
    SLIDER3 = Ttable[SQpnt]; SQSQ = Stable[SQpnt]; pp = "[AUTO MODE]"; 
  } else { 
    pp = "[MANUAL MODE]"; SLIDER1 = 0; SLIDER2 = 0; SLIDER3 = 30; 
  }    
}
// ============================================
//  Heater(23), Fan(9), Solenoid(29)
  long itime2, itime3; 
  int Fcnt = 0;             // 0 to 64 FAN on/off rate 
  int Hcnt = 0;             // 0 to 64 HEATER on/off rate 
  int timeup;               // 
// ============================================
void solenoid() {
  if(SimbleeForMobile.updatable) { SimbleeForMobile.updateValue(doorbtn, DOOR); }; 
  digitalWrite(29,  1); delay(1500); digitalWrite(29,  0); DOOR = 0;
  if(SimbleeForMobile.updatable) { SimbleeForMobile.updateValue(doorbtn, DOOR); };  
}
void FanHeat(int fanset, int heatset) { // fanset/heatset 0-63
  if(fanset > 20) { timeup = 300; } else { timeup = 9000; }
  if(micros() - itime2 > timeup) { itime2 = micros(); Fcnt++; if(Fcnt > 63) { Fcnt = 0; }         // FAN Control
      if(Fcnt <= fanset) { if(fanset) { digitalWrite( 9, 1); } } else { digitalWrite( 9, 0); }    // FAN ON /OFF  
  } 
  if(!fanset) { digitalWrite( 9, 0); }
  if(SFan)    { digitalWrite( 9, 1); }  // stirrer fan
  if(millis() - itime3 > 50)  { itime3 = millis(); Hcnt++; if(Hcnt > 63) { Hcnt = 0; }            // HEATER Control
    if(heatset > 10 && Hcnt <= heatset) { digitalWrite(23, 1); } else { digitalWrite(23, 0); }    // HEATER ON/OFF  
  } 
  //--------------------------------------------
  if(TCtemp > 280) { digitalWrite(23, 0); } // heater off for safe
  //--------------------------------------------
}
// ============================================
//  TEMP (Ktype -200 to 700degree)
//  D[31-18]:14bit temp (LSB = 0.25degree)
//  D[16]:fault D[17,3]:0 D[15-4]:internal temp (LSB = 0.0625degree)
//  D[2]:vcc  D[1]:gnd  D[0]:open
  SPISettings MAX31855(SPI_CLOCK_DIV8, MSBFIRST, SPI_MODE1);
  byte MAX[4];              // MAX SPI read buffer  
// ============================================
int Rtemp() {
   int flt = 0; read31855();
   if(bitRead(MAX[2], 0) || bitRead(MAX[0], 0) || bitRead(MAX[0], 1) || bitRead(MAX[0], 2)) { flt = 1; }
   if(flt) {
      delay(300); read31855();
      if(bitRead(MAX[2], 0)) { Serial.print("Sensor FAULT"); }
      if(bitRead(MAX[0], 0)) { Serial.print("Short to VCC"); }
      if(bitRead(MAX[0], 1)) { Serial.print("Short to GND"); }
      if(bitRead(MAX[0], 2)) { Serial.print("Open circuit"); }          
   }
   return word(MAX[3], MAX[2])/16;           
}
void read31855() {
   SPI.beginTransaction(MAX31855); 
   digitalWrite(19, 0);     // CS "L"
   MAX[3] = SPI.transfer(0); MAX[2] = SPI.transfer(0); 
   MAX[1] = SPI.transfer(0); MAX[0] = SPI.transfer(0);  // read 32bit        
   digitalWrite(19, 1);     // CS "H"
   SPI.endTransaction();    //  
}
